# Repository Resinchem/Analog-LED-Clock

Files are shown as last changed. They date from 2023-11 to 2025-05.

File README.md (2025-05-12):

## Analog-LED-Clock
This project started as a way to demonstrate the use of MCP23017 port expanders with ESP boards.  I decided to take the original breadboard version and use it to create my first custom PCB. I also added some additional features to the final clock.

ClockFace_Final_Github2

This particular project was primarily about the journey of designing and using a custom PCB.  If you want to know more about this particular project, please refer to the following:
- [Unlocking the Power of PCBs](https://youtu.be/uTdGtw9cBE4) - YouTube Video
- [When It's Time to Create a Custom PCB](https://resinchemtech.blogspot.com/2023/11/custom-pcb-time.html) - Written blog article

If you want to know more about the MCP23017 port expanders, I cover those in the following:
- [MCP23017 Port Expander and ESPHome: Add More I/O Pins to Your Project](https://youtu.be/GyHiSyoyk_0) - YouTube video
- [Add up to 128 I/O Pins to your ESP Board](https://resinchemtech.blogspot.com/2023/10/IO-expander.html) - Written blog article

### The clock controller code, PCB design files and the 3D .stl files are shared here "AS-IS"!

The files are being shared here primarily as support for the above video and blog article and for those that wish to learn more about how it works, or to use my version as a framewwork for their own project.  And while I will provide some general information in each folder's README file and a little more in the wiki, it is unlikely I will continue to make enhancements.  And while the PCB was designed to also accommodate an ESP32 mini instead of the D1 Mini/ESP8266, I do not intend to release an ESP32 version.  **PLEASE DON'T ASK!**<br><br />
If you wish to use an ESP32, clone or fork the repository and update the libraries and GPIO pins for the ESP32 mini.  I will not be accepting PRs, issue reports or enhancement requests for this repo.  If you have questions or comments, please post those in the comment section of the above video or blog article.

It takes substantial time, effort and cost to develop and maintain this repository. If you find it helpful and would like to say 'thanks', please consider supporting this project and future development:

<a href="https://www.buymeacoffee.com/resinchemtech" target="_blank">Buy Me A Coffee</a>

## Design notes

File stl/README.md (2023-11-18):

## 3D Printed Parts Design (.stl) Files

These are the .stl files for all the 3D printed parts I used for the clock project.  All parts were printed using PLA on a Creality Ender 3 Pro.  Supports were not needed, although you may wish to add them for the clock stand.

**Important Note**: The clock face has a diameter of 215 mm.  Be sure this will fit on your build plate.  For me, it was necessary to disable the skirt for the print to fit.

|File | Part Description
-----|-----
|Clock Face.stl | The front clock face
|Clock Stand.stl | The desk stand to hold the clock in a slightly canted postion
|ILI9341 Display Trim.stl | A small trim piece to super glue to the clock face around the display opening
|Number Covers.stl | Small blocks to glue over the back clock face number cutouts to block light bleedover
|Standoff Mounts.stl | Mounts to super glue to the back of clock face for mounting the threaded ends of M3 brass stand-offs.

stl_parts_01

stl_parts_02

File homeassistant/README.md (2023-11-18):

## Home Assistant Related Files

These are ***example*** files from my Home Assistant installation for integrating and controlling the clock in Home Assistant via MQTT.  It is highly unlikely you can just copy/paste these examples directly into your Home Assistant and expect them to work due to difference in entity names and other variations.

I use packages in my Home Assistant.  This means that integrations like sensor:, automation:, etc. can be repeated between packages.  If you are not using packages, then you will need to split out these various integration/entities and place them under the appropriate section of your own configuration.

### analog_clock.yaml

This is the primary package for the integration of the clock.  It shows how the MQTT sensors and switches are used to both receive the state of the clock and to control it.  It also has a couple of example automations using the clock. There is additional documentation withing the file itself.

### dashboard.yaml

HomeAssistant_Dashboard

This contains the YAML used to create the above dashboard.  Again, you will need to modify this for your own entities/installation.  It also used two custom components, installed via the Home Assistant Community Store (HACS):

- [Custom Button Card](https://github.com/custom-cards/button-card) by @RomRider (v3.5.0)
- [Text Divider Row](https://github.com/iantrich/text-divider-row) by iantrich (v1.4.0)*

*Note that the current 1.4.1 version of the text divider has a visible background. Install v1.4.0 if you don't want this boarder/background.

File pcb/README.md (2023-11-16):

## PCB Design and Related Files

The files in this folder are the design files for the clock PCB.  The JSON files can be imported directly into EasyEDA if you wish to review or modify them.

- Analog Clock Schematic.json: The schematic file for the project
- Analog Clock PCB.json: The PCB design file for the project

The Gerber.zip files are all the files needed to place an order for the PCB via any manufacturer.

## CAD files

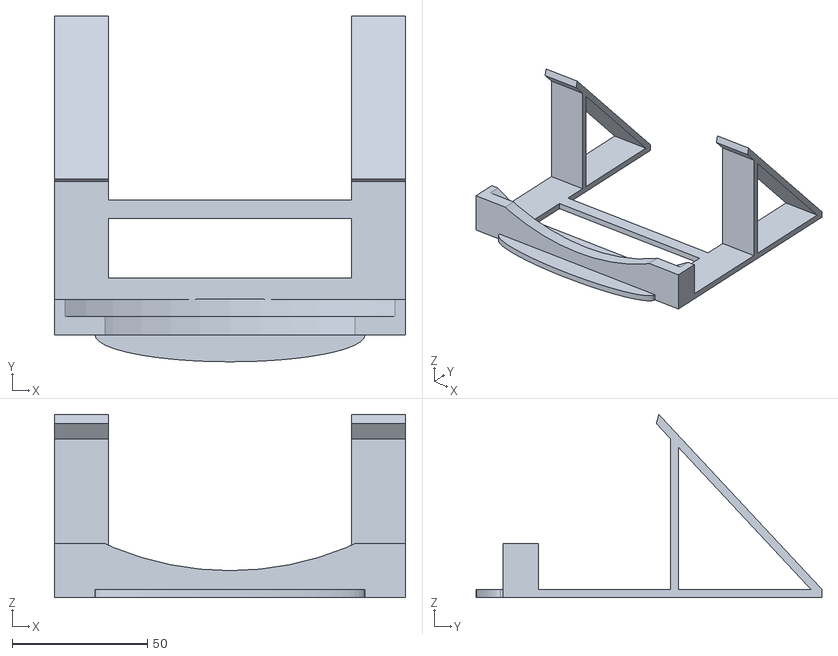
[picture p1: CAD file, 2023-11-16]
stl/Clock Stand.stl
130.0 x 128.0 x 67.9

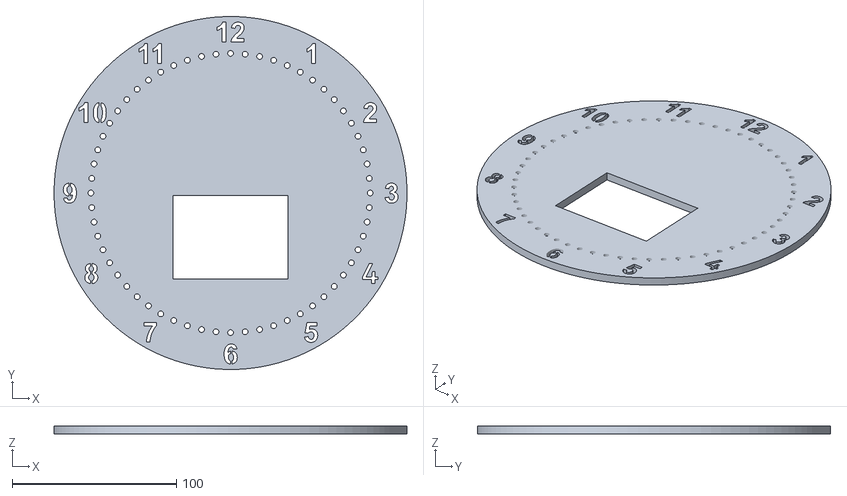
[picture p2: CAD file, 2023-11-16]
stl/Clock Face.stl
215.0 x 215.0 x 5.00

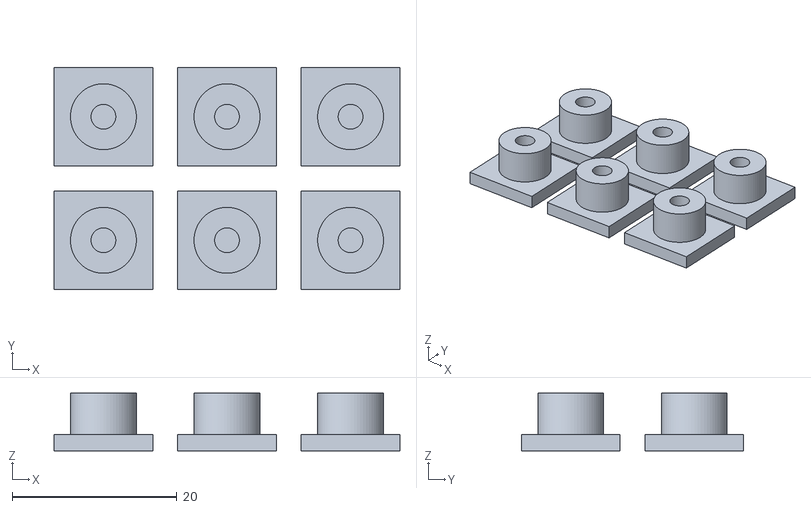
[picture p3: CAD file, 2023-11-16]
stl/Standoff Mounts.stl
42.0 x 27.0 x 7.00

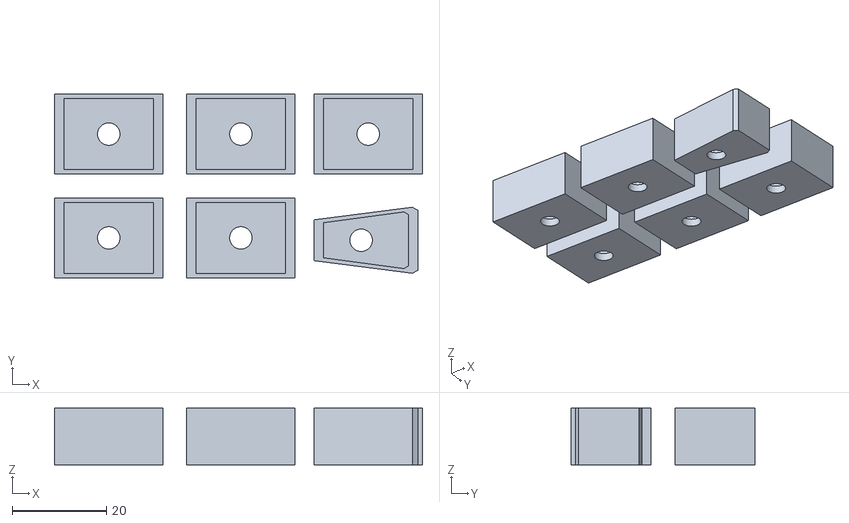
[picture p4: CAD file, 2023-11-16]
stl/Number Covers.stl
78.0 x 39.0 x 12.0

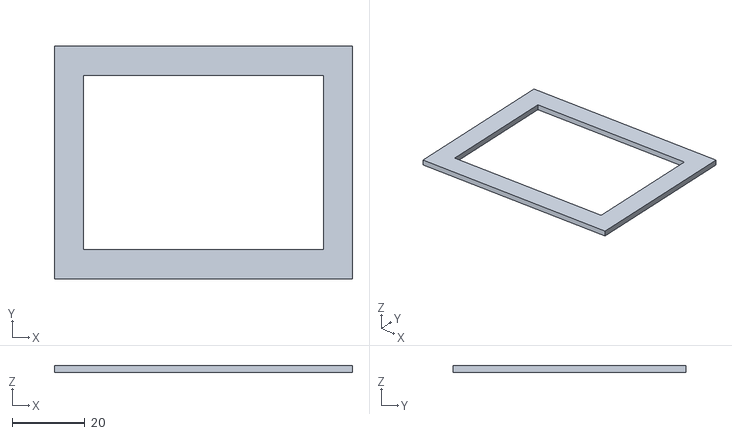
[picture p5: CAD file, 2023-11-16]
stl/ILI9341 Display Trim.stl
82.0 x 64.0 x 2.00

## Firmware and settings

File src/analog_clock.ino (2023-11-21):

/* ==========================================================================================
   Analog LED Clock
   Sketch to control LEDs for a circular analog-style clock where the LEDs represent minutes
   and hours.  Options include different minute display modes.  See the wiki for more.
   Credentials.h and Settings.h must be located in same folder as this .ino file and both should
   be edited for your wifi/MQTT broker and pin/wiring configuration.

   MQTT is optional, but without it changes to some options (blink and sweep) will require modifying
   the Settings.h file and a recompile/OTA update.  In addition, code/source will need to be added
   to get current time, with an update each minute.  One option would be to implement a call
   to an NTP server.

   See the wiki for complete details  Offered "as-is" for adaption to your own projects.  PR
   and feature enhancement requests will not be accepted for this project.
   
   Board: LOLIN(WEMOS) D1, R2 & mini (other boards or ESP32 may require library/code changes)
   v1.02 Nov. 2023
   Resinchem Tech - licensed under Creative Commons Attribution-NonCommercial-ShareAlike 4.0 International License
   =========================================================================================*/
#include <ESP8266WiFi.h>
#include <ESP8266mDNS.h>
#include <ESP8266WebServer.h>
#include <WiFiUdp.h>
#include <ArduinoOTA.h>
#include <FS.h>
#include "Credentials.h"          //File must exist in same folder as .ino.  Edit as needed for project
#include "Settings.h"             //File must exist in same folder as .ino.  Edit as needed for project
#include <Adafruit_MCP23X17.h>    // https://github.com/adafruit/Adafruit-MCP23017-Arduino-Library
#include <Wire.h>                 // for I2C
#if defined(MQTTMODE) && (MQTTMODE == 1 && (WIFIMODE == 1 || WIFIMODE == 2))
  #include <PubSubClient.h>
#endif

#define RED_BUTTON 13   //hour MCP board push button pins
#define YELLOW_BUTTON 14
#define GREEN_BUTTON 15

//GLOBAL VARIABLES (MQTT and OTA Updates)
bool mqttConnected = false;       //Will be enabled if defined and successful connnection made.  This var should be checked upon any MQTT actin.
long lastReconnectAttempt = 0;    //If MQTT connected lost, attempt reconnenct
uint16_t ota_time = ota_boot_time_window;
uint16_t ota_time_elapsed = 0;           // Counter when OTA active

//Other Globals
String haTime = "00:00";  // Provide default time until HA updates at top of each minute
String haDate= "2023-00-00"; //Currently only used for last boot date/time
byte hours = 0;
byte minutes = 0;
bool firstBoot = true;  //Needed for logging boot time, which is not available during setup.

bool ledsOn = true;  // Default at boot - can be toggled via button or MQTT
int numSegments = 0;
int lastSegmentMins = 0;
int curSegment = 0;  // current segment (0-3) for the current minute
int curMinute = 0;   // current minute (0-14) within the segment
unsigned long prevTime = 0;  //Main loop timer

//Define MCP boards
Adafruit_MCP23X17 mcp_hour;  //0x20
Adafruit_MCP23X17 mcp_min[4];  //Array from 0-3 for the four quadrant 0-14, 15-29, 30-44, 45-59

//Array for hour pins, which are physically reversed on clock (first element[0] unused)
byte hour_pin[13] = {0, 11, 10, 9, 8, 7, 6, 5, 4, 3, 2, 1, 12};

/*Array for minute pins, which are off by one (pin 1 is minute 0, pin 2 is minute 1, etc.)
  array[0] is first LED in segment (e.g. 0, 15, 30, 45), then array[1] aligns with first minute in each (e.g. 1, 16, 31, 46).
  Loops should be configured for i = 0; i < 15
*/
byte min_pin[15] = {1, 2, 3, 4, 5, 6, 7, 8, 9, 10, 11, 12, 13, 14, 15};  //Segment LEDs 0-14, 15-29, 30-44, 45-59, where array[0] = 0, 15, 30 and 45

//Setup Local Access point if enabled via WIFI Mode
#if defined(WIFIMODE) && (WIFIMODE == 0 || WIFIMODE == 2)
  const char* APssid = AP_SSID;        
  const char* APpassword = AP_PWD;  
#endif

//Setup Wifi if enabled via WIFI Mode
#if defined(WIFIMODE) && (WIFIMODE == 1 || WIFIMODE == 2)
  const char *ssid = SID;
  const char *password = PW;
#endif

//Setup MQTT if enabled - only available when WiFi is also enabled
#if (WIFIMODE == 1 || WIFIMODE == 2) && (MQTTMODE == 1)    // MQTT only available when on local wifi
  const char *mqttUser = MQTTUSERNAME;
  const char *mqttPW = MQTTPWD;
  const char *mqttClient = MQTTCLIENT;
  const char *mqttTopicSub = MQTT_TOPIC_SUB;
 // const char *mqttTopicPub = MQTT_TOPIC_PUB;
#endif

WiFiClient espClient;
ESP8266WebServer server;
#if defined(MQTTMODE) && (MQTTMODE == 1 && (WIFIMODE == 1 || WIFIMODE == 2))
  PubSubClient client(espClient);
#endif


//------------------------------
// Setup WIFI
//-------------------------------
void setup_wifi() {
  WiFi.setSleepMode(WIFI_NONE_SLEEP);  //Disable WiFi Sleep
  delay(200);
  // WiFi - AP Mode or both
#if defined(WIFIMODE) && (WIFIMODE == 0 || WIFIMODE == 2) 
  WiFi.mode(WIFI_AP_STA);
  WiFi.softAP(APssid, APpassword);    // IP is usually 192.168.4.1
#endif
  // WiFi - Local network Mode or both
#if defined(WIFIMODE) && (WIFIMODE == 1 || WIFIMODE == 2) 
  byte count = 0;

  WiFi.hostname(WIFIHOSTNAME);
  WiFi.begin(ssid, password);
  #if defined(SERIAL_DEBUG) && (SERIAL_DEBUG == 1)
    Serial.print("Connecting to WiFi");
  #endif
  while (WiFi.status() != WL_CONNECTED) {
    #if defined(SERIAL_DEBUG) && (SERIAL_DEBUG == 1)
      Serial.print(".");
    #endif
    // Stop if cannot connect
    if (count >= 60) {
      // Could not connect to local WiFi 
      #if defined(SERIAL_DEBUG) && (SERIAL_DEBUG == 1)
        Serial.println();
        Serial.println("Could not connect to WiFi.");   
      #endif  
      return;
    }
    delay(500);
    count++;
  }
  #if defined(SERIAL_DEBUG) && (SERIAL_DEBUG == 1)
    Serial.println();
    Serial.println("Successfully connected to Wifi");
    IPAddress ip = WiFi.localIP();
    Serial.println(WiFi.localIP());
  #endif
#endif   
};

// ===================================
//  SETUP MQTT AND CALLBACKS
// ===================================
void setup_mqtt() {
#if defined(MQTTMODE) && (MQTTMODE == 1 && (WIFIMODE == 1 || WIFIMODE == 2))
  byte mcount = 0;
  //char topicPub[32];
  client.setServer(MQTTSERVER, MQTTPORT);
  client.setCallback(callback);
  #if defined(SERIAL_DEBUG) && (SERIAL_DEBUG == 1)
    Serial.print("Connecting to MQTT broker.");
  #endif
  while (!client.connected( )) {
    #if defined(SERIAL_DEBUG) && (SERIAL_DEBUG == 1)
      Serial.print(".");
    #endif
    client.connect(mqttClient, mqttUser, mqttPW);
    if (mcount >= 60) {
      #if defined(SERIAL_DEBUG) && (SERIAL_DEBUG == 1)
        Serial.println();
        Serial.println("Could not connect to MQTT broker. MQTT disabled.");
      #endif
      // Could not connect to MQTT broker
      return;
    }
    delay(500);
    mcount++;
  }
  #if defined(SERIAL_DEBUG) && (SERIAL_DEBUG == 1)
    Serial.println();
    Serial.println("Successfully connected to MQTT broker.");
  #endif
  client.subscribe(MQTT_TOPIC_SUB"/#");
  client.subscribe(MQTT_TOPIC_SUB2"/#");
  client.publish(MQTT_TOPIC_PUB"/mqtt", "connected", true);
  mqttConnected = true;
#endif
}

void reconnect() {
  int retries = 0;
#if defined(MQTTMODE) && (MQTTMODE == 1 && (WIFIMODE == 1 || WIFIMODE == 2))
  while (!client.connected()) {
    if(retries < 150)
    {
      #if defined(SERIAL_DEBUG) && (SERIAL_DEBUG == 1)
        Serial.print("Attempting MQTT connection...");
      #endif
      if (client.connect(mqttClient, mqttUser, mqttPW)) 
      {
        #if defined(SERIAL_DEBUG) && (SERIAL_DEBUG == 1)
          Serial.println("connected");
        #endif
        // ... and resubscribe
        client.subscribe(MQTT_TOPIC_SUB"/#");
        client.subscribe(MQTT_TOPIC_SUB2"/#");
      } 
      else 
      {
        #if defined(SERIAL_DEBUG) && (SERIAL_DEBUG == 1)
          Serial.print("failed, rc=");
          Serial.print(client.state());
          Serial.println(" try again in 5 seconds");
        #endif
        retries++;
        // Wait 5 seconds before retrying
        delay(5000);
      }
    }
    if(retries > 149)
    {
    ESP.restart();
    }
  }
#endif
}

void callback(char* topic, byte* payload, unsigned int length) {
  payload[length] = '\0';
  String message = (char*)payload;
  /*
   * Add any commands submitted here
   * Example:
   * if (strcmp(topic, "cmnd/matrix/mode")==0) {
   *   MyVal = message;
   *   Do something
   *   return;
   * };
   */
  if (strcmp(topic, MQTT_TOPIC_SUB2"/hatime") == 0) {
     haTime = message;
     int colonLoc = haTime.indexOf(":");
     if (colonLoc > 0) {
       setTimeSegments();
       displayTime();
     }
     if ((firstBoot) && (haDate != "2023-00-00")) {
        updateMqttLastBoot();
        firstBoot = false;
     }
  } else if (strcmp(topic, MQTT_TOPIC_SUB2"/hadate") == 0) {
    haDate = message;
    if ((firstBoot) && (haTime != "00:00")) {
      updateMqttLastBoot();
      firstBoot = false;
    }
  } else if (strcmp(topic, MQTT_TOPIC_SUB"/dispmode") == 0) {
     int newMode = message.toInt();
     if ((newMode >= 0) && (newMode <= 4)) {  //Increment when new modes added and add to displayTime()
        dispMode = newMode;
        updateMqttDispMode();
        displayTime();
     }
  } else if (strcmp(topic, MQTT_TOPIC_SUB"/sweep") == 0) {  //Only used for display mode 0 (all leds)
      if ((message == "ON") || (message == "on") || (message == "1")) {
        sweepMinutes = true;
      } else {
        sweepMinutes = false;
      }
      updateMqttSweep();
      displayTime();
  } else if (strcmp(topic, MQTT_TOPIC_SUB"/blink") == 0) {
      if ((message == "ON") || (message == "on") || (message == "1")) {
        blinkCurMinute = true;
      } else {
        blinkCurMinute = false;
      }
      updateMqttBlink();
      displayTime();
  } else if (strcmp(topic, MQTT_TOPIC_SUB"/leds") == 0) {
    if ((message == "ON") || (message == "on") || (message == "1")) {
      ledsOn = true;
      displayTime();
    } else {
      ledsOn = false;
      allLEDsOff();
    }
    updateMqttLeds();
  } else if (strcmp(topic, MQTT_TOPIC_SUB"/test") == 0) {
    testLEDS();
  }
  
}

/* =============================================
 *  MAIN SETUP
 * =============================================
*/
void setup() {
  byte i;
  byte j;
  #if defined(SERIAL_DEBUG) && (SERIAL_DEBUG == 1)
    Serial.begin(115200);
    Serial.println("Starting setup....");
  #endif
  //Start I2C
  Wire.begin();

  #if defined(SERIAL_DEBUG) && (SERIAL_DEBUG == 1)
    Serial.println("Initializing expansion boards");
  #endif
  
  //*****************************************
  //Initialize all MCP Minute boards in array 
  //(update these if your board is configured differently)
  mcp_min[0].begin_I2C( 0x24 );     //segment 0-14 minutes
  mcp_min[1].begin_I2C( 0x23 );     //segment 15-29
  mcp_min[2].begin_I2C( 0x22 );     //segment 30-44
  mcp_min[3].begin_I2C( 0x21 );     //segment 45-59
  
  //Initialize hour board
  mcp_hour.begin_I2C( 0x20 );   //hour digits
  //*****************************************
 
  //for minute boards, set pins 1-15 for output (array[0] - array[14])
  for (j = 0; j < 4; j++) {              //boards 0-3
    for (i = 0; i < 15; i++) {           //pins 1-15
      mcp_min[j].pinMode(min_pin[i], OUTPUT);
    }
  }
  //for hour board, set pins 1-12 for output 
  for (i = 1; i < 13; i++) {
    mcp_hour.pinMode(hour_pin[i], OUTPUT);
  }
  
  //*******************************************
  //hour expansion board has three input buttons
  //update these if your board is wired differently
  mcp_hour.pinMode(RED_BUTTON, INPUT_PULLUP);  //pin 13
  mcp_hour.pinMode(YELLOW_BUTTON, INPUT_PULLUP); //pin 14
  mcp_hour.pinMode(GREEN_BUTTON, INPUT_PULLUP);  //pin 15
  //********************************************

  #if defined(SERIAL_DEBUG) && (SERIAL_DEBUG == 1)
    Serial.println("All pins configured");
  #endif
  
  // Turn off all LEDS (since some may be on from OTA update)
  allLEDsOff();
  //-----------------------------
  // Setup Wifi
  //-----------------------------
  //Turn on 12 to indicated booting, waiting on wifi
  mcp_hour.digitalWrite(hour_pin[12], HIGH);
  setup_wifi();

  //-----------------------------
  // Setup OTA Updates
  //-----------------------------
  //Turn on 3 to indicate setting up OTA
  mcp_hour.digitalWrite(hour_pin[3], HIGH);
  ArduinoOTA.setHostname(OTA_HOSTNAME);
  ArduinoOTA.onStart([]() {
    String type;
    if (ArduinoOTA.getCommand() == U_FLASH) {
      type = "sketch";
    } else { // U_FS
      type = "filesystem";
    }
    // NOTE: if updating FS this would be the place to unmount FS using FS.end()
  });
  ArduinoOTA.begin();
  // Setup handlers for web calls for OTAUpdate and Restart
  server.on("/restart",[](){
    server.send(200, "text/html", "<h1>Restarting...</h1>");
    delay(1000);
    ESP.restart();
  });
  server.on("/otaupdate",[]() {
    server.send(200, "text/html", "<h1>Analog Clock Ready for Update...<h1><h3>Start upload from IDE now</h3>");
    ota_flag = true;
    ota_time = ota_time_window;
    ota_time_elapsed = 0;
  });
  server.begin();

  //------------------------
  // Setup MQTT if Enabled
  //------------------------
  mcp_hour.digitalWrite(hour_pin[6], HIGH);
  setup_mqtt();

  //If MQTT setup and connected, request current time update from Home Assistant
#if defined(MQTTMODE) && (MQTTMODE == 1 && (WIFIMODE == 1 || WIFIMODE == 2))
  char outVal[5];
  if (mqttConnected) {
    client.publish(MQTT_TOPIC_PUB"/gettime", "1", false);
    delay(250);  //allow time to publish
    //Publish defaults states, in case different from last states before reboot
    updateMqttAll(); 
  }
#endif
  
  //Boot/setup complete, Turn off all hour LEDS
  //Turn off all hours (only 12 should be on)
  for (i = 1; i < 13; i++) {
    mcp_hour.digitalWrite(hour_pin[i], LOW);
  }
  
  #if defined(SERIAL_DEBUG) && (SERIAL_DEBUG == 1)
    Serial.println("Starting LED Test");
  #endif
  testLEDS();  
}

// ==================================
//   MAIN LOOP
// =================================

void loop() {
  unsigned long currentMillis = millis(); 
  
  //Handle OTA updates when OTA flag set via HTML call to http://ip_address/otaupdate
  if (ota_flag) {
    updateOTA();  //show OTA update on clock
    uint16_t ota_time_start = millis();
    while (ota_time_elapsed < ota_time) {
      ArduinoOTA.handle();  
      ota_time_elapsed = millis()-ota_time_start;   
      delay(10); 
    }
    ota_flag = false;
    allLEDsOff();
    //showTime(sweepMinutes);
    displayTime();
  }
  //Handle any web calls
  server.handleClient();
  //MQTT Calls
  #if defined(MQTTMODE) && (MQTTMODE == 1 && (WIFIMODE == 1 || WIFIMODE == 2))
    if (!client.connected()) 
    {
      reconnect();
    }
    client.loop();
  #endif

  //Process button presses
  //RED Button - Test LEDs
  if (!mcp_hour.digitalRead(RED_BUTTON)) {
    ledsOn = true;
    testLEDS();
    delay(250);
  }
  //YELLOW Button - Toggle LEDs off/on
  if (!mcp_hour.digitalRead(YELLOW_BUTTON)) {
    if (ledsOn) {
      ledsOn = false;
      allLEDsOff();
    } else {
      ledsOn = true;
      //showTime(sweepMinutes);
      displayTime();
    }
    updateMqttLeds();
    delay(250);
  }
  //GREEN Button - Change display mode
  if (!mcp_hour.digitalRead(GREEN_BUTTON)) {
    if (dispMode < 4) {
      dispMode = dispMode + 1;
    } else {
      dispMode = 0;
    }
    displayTime();
    updateMqttDispMode();
    delay(250);
  }
  
  if (ledsOn) {
    if (currentMillis - prevTime >= blinkInterval) {
      prevTime = currentMillis;
      if (blinkCurMinute) {
        blinkMinute();
      }
    }
  }
}

// =================================
//  Time and Time Display Functions
// =================================
void setTimeSegments() {
/* This function takes the current time as a string from MQTT (via Home Assistant) and breaks it 
   apart into hours and minutes as integers, converting 24 hours to 12 hour, and determining the
   the number of minute LED 15-minute segments that should be fully lit, along with the last
   segment and the number of LEDs that should be lit in this last segment for the current minute.
   It is called primarily from the MQTT callback each time a new time gets published (once a minute).
*/
   int colonLoc = haTime.indexOf(":");
   if (colonLoc > 0) {
     hours = (haTime.substring(0, colonLoc)).toInt();
     minutes = (haTime.substring(colonLoc + 1)).toInt();
     //handle 24 hour time reported by HA and just convert to hours 1-12
     if (hours > 12) {
       hours = hours - 12;
     } else if (hours == 0) {
       hours = 12;
     }
    // Determine number of segments fully or partially lit (using array segment values)
     if (minutes < 15) {
       numSegments = 0;
     } else if (minutes < 30) {
       numSegments = 1;
     } else if (minutes < 45) {
       numSegments = 2;
     } else {
       numSegments = 3;
     }
    //Determine number of LEDs in last segment
    lastSegmentMins = (minutes - (15 * (numSegments)) + 1);  //add one since each segment starts with zero
   }
}

void displayTime() {
/*  Provides a commonwrapper to call elsewhere in code so that each call doesn't need to check
    the current display mode.  This function will then call the appropriate function to display
    the time for the current display mode.  Add any new modes here and increment count in MQTT callback 
*/
   switch (dispMode) {
     case 0:   
       showTimeAll(sweepMinutes);
       break;
     case 1:
       showTime01();
       break;
     case 2:
       showTime05();
       break;
     case 3:
       showTime10();
       break;
     case 4:
       showTime15();
       break;
     default:
       break;
   }
}

void showTimeAll(bool sweepMin) {
/*  Default mode (dispMode 0).  Lights up all minute LEDs up to the current minute.
    If the sweepMin boolean is true (the default setting on boot is in the Settings.h file), 
    the LEDs are redrawn (sweep motion) each time the time is updated.  Otherwise,
    all the LEDs for the current minute as simply toggled on, giving the impression of each 
    new LED lighting as the minutes increase.  Can also be anabled/disabled via MQTT.
*/
  //if firstTime flag is true, minute leds will light in sequence with short delay, like the LED test
  byte i;
  byte j;
  byte r;

  if (ledsOn) {
    // HOURS
    //Light up hour LED (and assure all others are off)
    for (i = 1; i < 13; i++) {
      if (i == hours) {
        mcp_hour.digitalWrite(hour_pin[i], HIGH);
      } else {
        mcp_hour.digitalWrite(hour_pin[i], LOW);
      }
    }

    // MINUTES
    //If sweep mode enabled, first turn off all minute LEDs
    if (sweepMin) {
      if (minutes == 0) {
        //if top of hour, reverse sweep all LEDs off
        minLEDsOff(true); 
      } else {
        //just turn off all lit minuted LEDS
        minLEDsOff(false);
      }
    }
    
    //Loop through all four segments, lighting all LEDs if current segment less than the last
    for (j = 0; j < 4; j++) {
      if (j < numSegments) {
        //Light all LEDs in segement
        for (i = 0; i < 15; i++) {
          mcp_min[j].digitalWrite(min_pin[i], HIGH);
           if (sweepMin) {
             delay(50);
           }
        }
      } else if (j == numSegments) {
        //Only light LEDs for lastSegmentMins
        for (i = 0; i < lastSegmentMins; i++) {
          mcp_min[j].digitalWrite(min_pin[i], HIGH);
          if (sweepMin) {
            delay(50);
          }
          r = i;
          // Capture last LED position for blinking
          curSegment = j;
          curMinute = i;
        }
        //Turn off any remaining lights in this segment
        for (i = (r + 1); i < 15; i++) {
          mcp_min[j].digitalWrite(min_pin[i], LOW);
        }
      } else {
        //Turn off all remaining LEDs (needed for rollover to new hour)
        for (i = 0; i < 15; i++) {
          mcp_min[j].digitalWrite(min_pin[i], LOW);
        }
      }
    }
  } else {
    //No current time from HA yet (usually on startup)
    //Request refresh of time from HA via MQTT
  }
}

void showTime01() {
/*  dispMode 1... only show current minute LED (one LED lit at a time).
    Blink mode still supported but will ignore/not use any sweep actions
*/
  byte i;

  if (ledsOn) {
    // HOURS
    //Light up hour LED (and assure all others are off)
    for (i = 1; i < 13; i++) {
      if (i == hours) {
        mcp_hour.digitalWrite(hour_pin[i], HIGH);
      } else {
        mcp_hour.digitalWrite(hour_pin[i], LOW);
      }
    }

    //MINUTES
    //Turn off all minute LEDs (no sweep), this will turn off the previous minute
     minLEDsOff(false);
     //Just turn on proper LED in last segment 
     mcp_min[numSegments].digitalWrite(min_pin[lastSegmentMins-1], HIGH);
     // Capture last LED position for blinking
     curSegment = numSegments;
     curMinute = lastSegmentMins-1; 
  }
}
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

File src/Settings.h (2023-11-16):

// =====================================================================================
// Update/Add any #define values to match your build and board type if not using D1 Mini
// =====================================================================================
// v1.01

#define WIFIMODE 2                            // 0 = Only Soft Access Point, 1 = Only connect to local WiFi network with UN/PW, 2 = Both
#define WIFIHOSTNAME "ANALOG_CLOCK"           // Host name for WiFi/Router
#define MQTTMODE 1                            // 0 = Disable MQTT, 1 = Enable (will only be enabled if WiFi mode = 1 or 2 - broker must be on same network)
#define MQTTCLIENT "analog_clock"             // MQTT Client Name
#define MQTT_TOPIC_SUB "cmnd/aclock"          // Default MQTT subscribe topic for commands to this device
#define MQTT_TOPIC_SUB2 "stat/tm1638"         // Secondary MQTT subscribe topic for general shared data/topics (e.g. date, time, etc. from TM1638 via Home Assistant)
#define MQTT_TOPIC_PUB "stat/aclock"          // Default MQTT publish topic
#define OTA_HOSTNAME "ANALOG_CLOCK_OTA"       // Hostname to broadcast as port in the IDE of OTA Updates
#define SERIAL_DEBUG 1                        // 0 = Disable (must be disabled if using RX/TX pins), 1 = enable

// ---------------------------------------------------------------------------------------------------------------
// Options - Defaults upon boot-up or any other custom ssttings
// ---------------------------------------------------------------------------------------------------------------
// OTA Settings
bool ota_flag = true;                    // Must leave this as true for board to broadcast port to IDE upon boot
uint16_t ota_boot_time_window = 2500;    // minimum time on boot for IP address to show in IDE ports, in millisecs
uint16_t ota_time_window = 20000;        // time to start file upload when ota_flag set to true (after initial boot), in millsecs

// Other options - boot defaults
bool blinkCurMinute = true;              //Blink current minute LED per interval cycle
uint16_t blinkInterval = 1000;           //Blink interval (1/2 cycle) in milliseconds
bool sweepMinutes = true;                //Sweep minute refresh on each update (redraws each minute from 1 to current - only dispMode 0)
byte dispMode = 0;                       //Default display mode at boot, currently 0-4 (see docs for modes)
